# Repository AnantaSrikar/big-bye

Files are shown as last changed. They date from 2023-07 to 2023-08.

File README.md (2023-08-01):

# big-bye
A project that encompasses (almost) all the knowledge and skills I acquired throughout my undergraduate degree, serving as a farewell gift! 

The skills / tools I used
- Programming (C. Python, bash, etc)
- Server Setup (Web server with HTTPS by Caddy)
- Network Setup (Its currently hosted on my HomeLab)
- Soldering (Perfboard and SMD)
- PCB Desigining
- 3D Modelling (A case was supposed to be designed, didn't happen due to logistical issues)

## Components
- [Firmware](/firmware/)
- [Web Server](/web_server/)

You can find a demo of the project [here](https://youtu.be/nfPE4j3Xo48)!

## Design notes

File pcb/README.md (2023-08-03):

# PCB
Here are the KiCAD files for the PCB that I designed for this project.

You can find the BOM [here](bom.csv).

The ST7735 Display can be found at this [link](https://robu.in/product/1-8-inch-spi-128160-tft-lcd-display-module-pcb-arduino/).

## Schematic
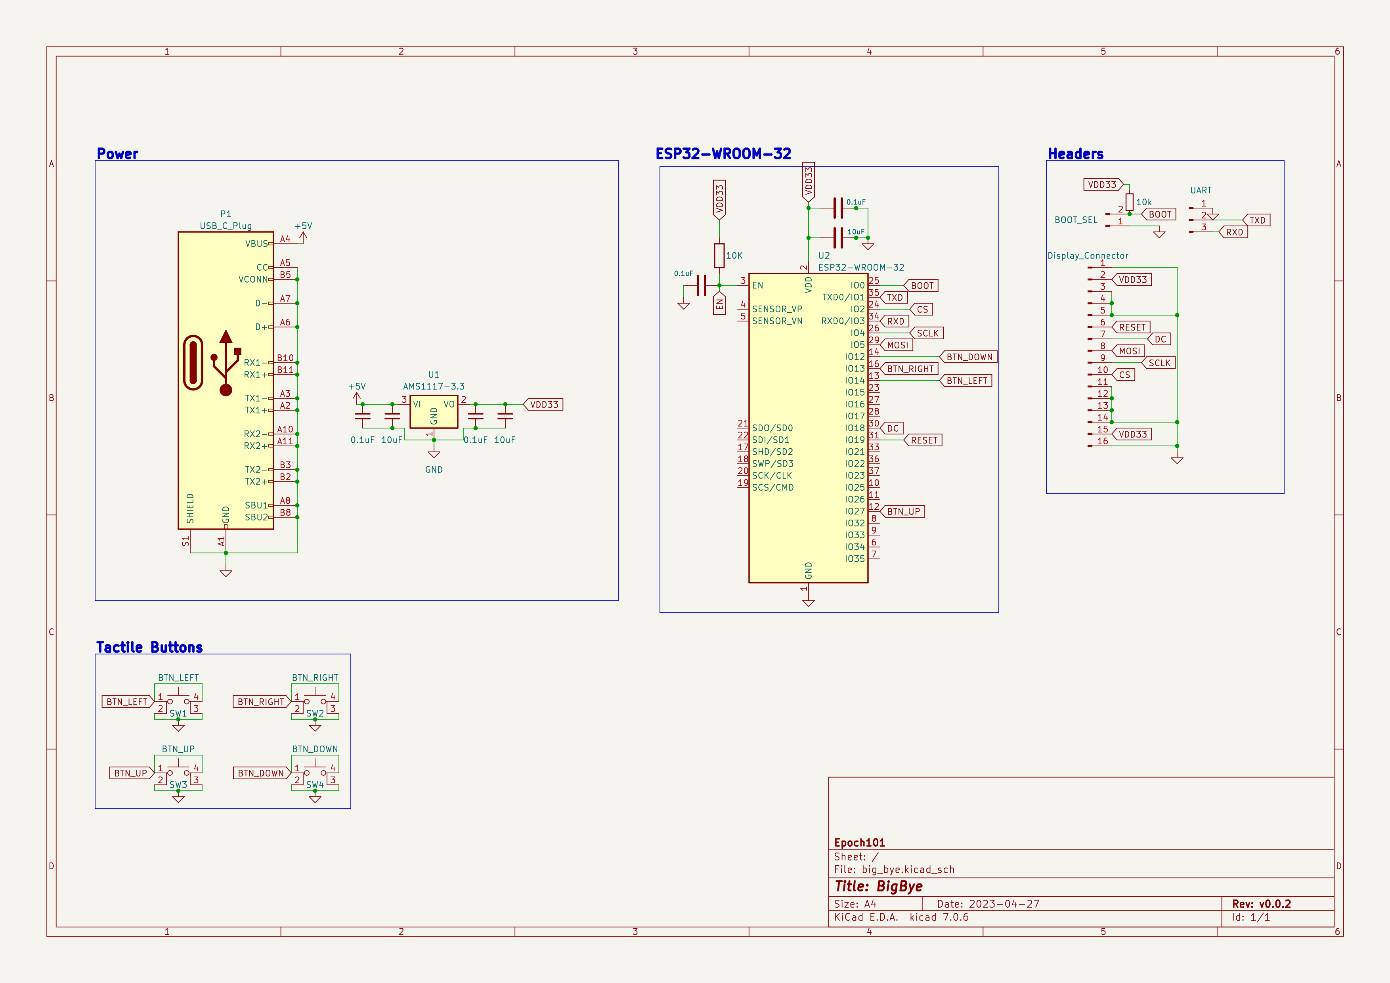
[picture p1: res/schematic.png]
The Schematic should be here, but not sure why it isn't :(


The PCB looks something like this:

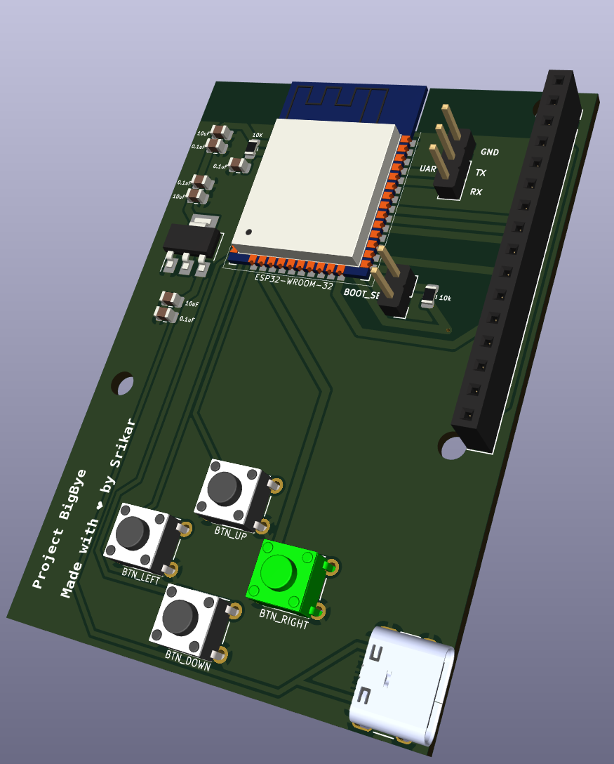
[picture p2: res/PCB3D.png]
The PCB should be here, but not sure why it isn't :(


You can watch a demo of the project in action (with the PCB and the display) [here](https://youtu.be/nfPE4j3Xo48)!

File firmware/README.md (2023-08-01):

# ESP32 Firmware

This firmware runs on the ESP32, which manages the Wi-Fi connection and fetches messages from a web server. These messages are then displayed on a TFT display.

## Features:
1. Dynamic WiFi Provisioning using ESP SoftAP Provisioning, available on both [Android](https://play.google.com/store/apps/details?id=com.espressif.provsoftap&hl=en&gl=US) and [iOS](https://apps.apple.com/ms/app/esp-softap-provisioning/id1474040630).
2. Dynamically loads the heading and messages onto the screen.
3. Support for combo button presses. Currently, UP + DOWN buttons work for resetting the board.
4. Works with BasicAuth for increased user privacy.

## Arduino IDE Setup
To run this on an ESP32, make sure the following settings are configured in the Arduino IDE:

1. Install the libraries mentioned in [dependencies.txt](/firmware/dependencies.txt).
2. Configure the Arduino IDE as shown below:

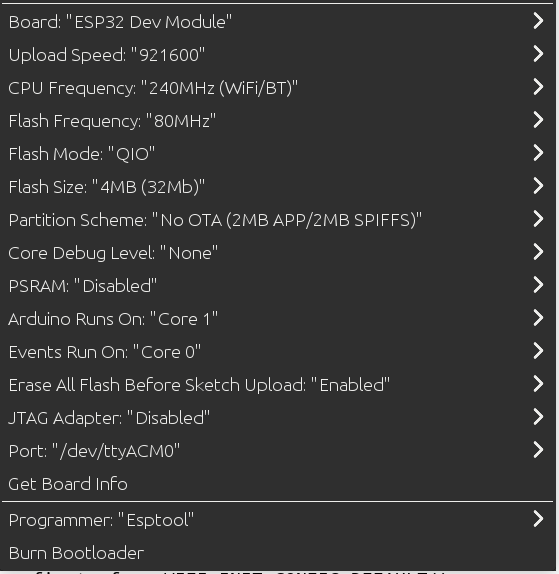
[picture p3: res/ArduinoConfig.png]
Arduino Config setting should be here, but not sure why it isn't :(


I'm using an ESP32-WROOM-32 with a 4MB Flash size; hence, I'm using the respective Partition Scheme to fit the application. Feel free to modify that as per your storage options.

## Flashing Firmware:
1. Set up your connection to the ESP32 via its UART port to flash it.
2. Make sure the ESP32 is booted in the Firmware Download Mode.
3. Select the right serial port in the Arduino IDE.
4. Modify `USERNAME`, `SERVER_ADDR`, `BASICAUTH_USERNAME`, and `BASICAUTH_PASSWORD` according to your [web server](../web_server) configuration.
5. Compile and wait for the flashing to be done.

## User Privacy
To ensure user privacy, the web server will be protected with BasicAuth using [Caddy](https://caddyserver.com/).

However, assigning usernames that are hard to guess will further increase privacy. For example, "somerandomdude-42069" would be hard to guess.

## Web Server
Head over [here](/web_server/) to set up your web server.

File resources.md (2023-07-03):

# Resources
## ESP32 Flashing
- https://www.reddit.com/r/esp32/comments/s8oeff/unable_to_program_esp32_module_on_a_custom_board/
- https://www.reddit.com/r/esp32/comments/kd90uy/esp32wroom32_custom_pcb_not_working_schematic/
- https://www.reddit.com/r/esp32/comments/ih0qxz/my_first_esp32_custom_pcb/

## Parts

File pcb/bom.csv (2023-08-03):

Id | Designator | Footprint | Quantity | Designation | Supplier and ref
1 | R2 | R_0805_2012Metric | 1 | 10k
2 | C7,C5,C1 | C_0805_2012Metric | 3 | 10uF
3 | C4,C3,C2,C6 | C_0805_2012Metric | 4 | 0.1uF
4 | P1 | USB_C_Receptacle_HRO_TYPE-C-31-M-12 | 1 | USB_C_Plug
5 | J2 | PinHeader_1x02_P2.54mm_Vertical | 1 | BOOT_SEL
6 | SW3 | SW_TH_Tactile_Omron_B3F-10xx | 1 | BTN_UP
7 | U2 | ESP32-WROOM-32 | 1 | ESP32-WROOM-32
8 | J1 | PinHeader_1x03_P2.54mm_Vertical | 1 | UART
9 | J3 | PinSocket_1x16_P2.54mm_Vertical | 1 | Display_Connector
10 | SW1 | SW_TH_Tactile_Omron_B3F-10xx | 1 | BTN_LEFT
11 | SW4 | SW_TH_Tactile_Omron_B3F-10xx | 1 | BTN_DOWN
12 | R1 | R_0805_2012Metric | 1 | 10K
13 | U1 | SOT-223-3_TabPin2 | 1 | AMS1117-3.3
14 | SW2 | SW_TH_Tactile_Omron_B3F-10xx | 1 | BTN_RIGHT

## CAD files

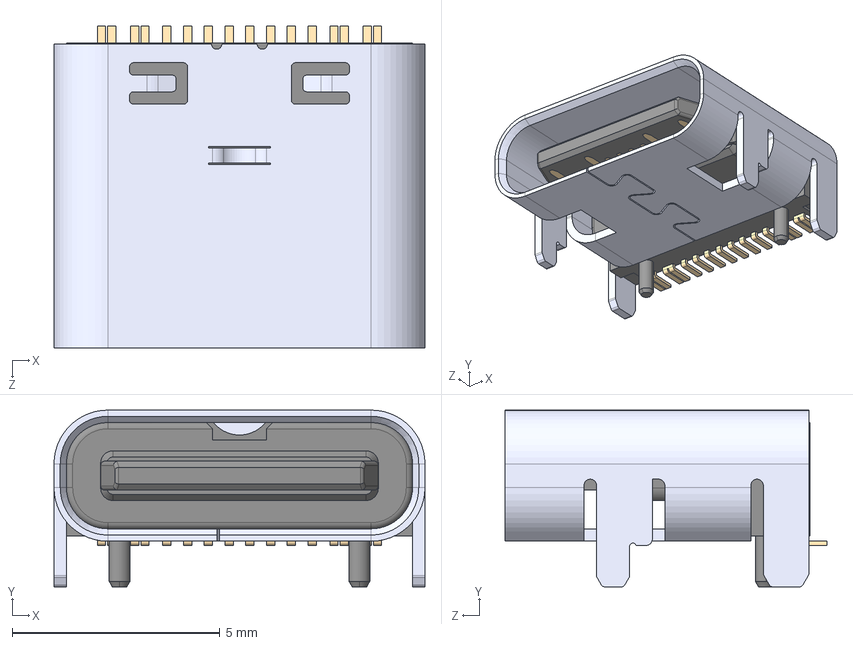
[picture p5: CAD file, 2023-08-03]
pcb/3d_models/CSP-USC16-TR--3DModel-STEP-468060.STEP
8.94 x 4.26 x 7.75 mm

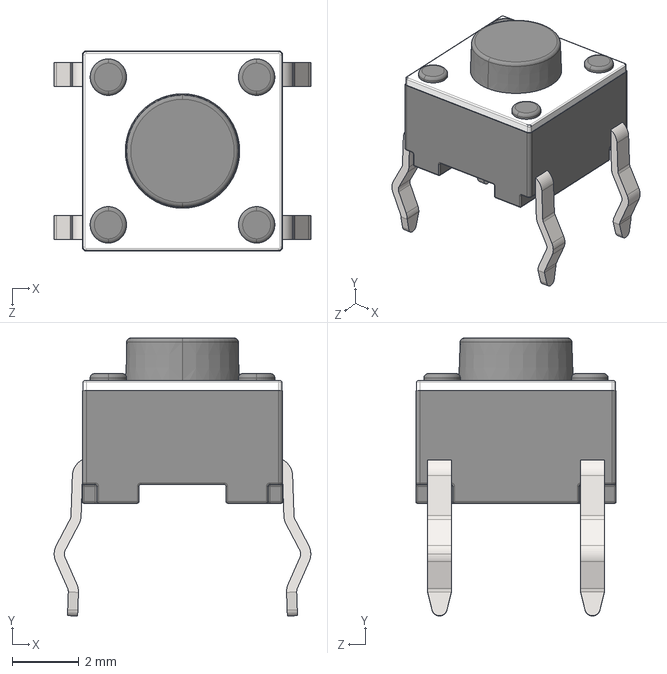
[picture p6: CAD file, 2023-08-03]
pcb/3d_models/tactile-switch-short-1.snapshot.1/tactileswitch-short/tactileswitch-short.STEP
7.69 x 8.33 x 6.01 mm

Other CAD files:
pcb/3d_models/tactile-switch-short-1.snapshot.1/tactileswitch-short/tactileswitch-short.IGS
pcb/3d_models/tactile-switch-short-1.snapshot.1/tactileswitch-short/tactileswitch-short.SLDPRT
pcb/3d_models/tactile-switch-short-1.snapshot.1/tactileswitch-short/tactileswitch-short.STL
pcb/3d_models/tactile-switch-short-1.snapshot.1/tactileswitch-short/tactileswitch-short.x_t

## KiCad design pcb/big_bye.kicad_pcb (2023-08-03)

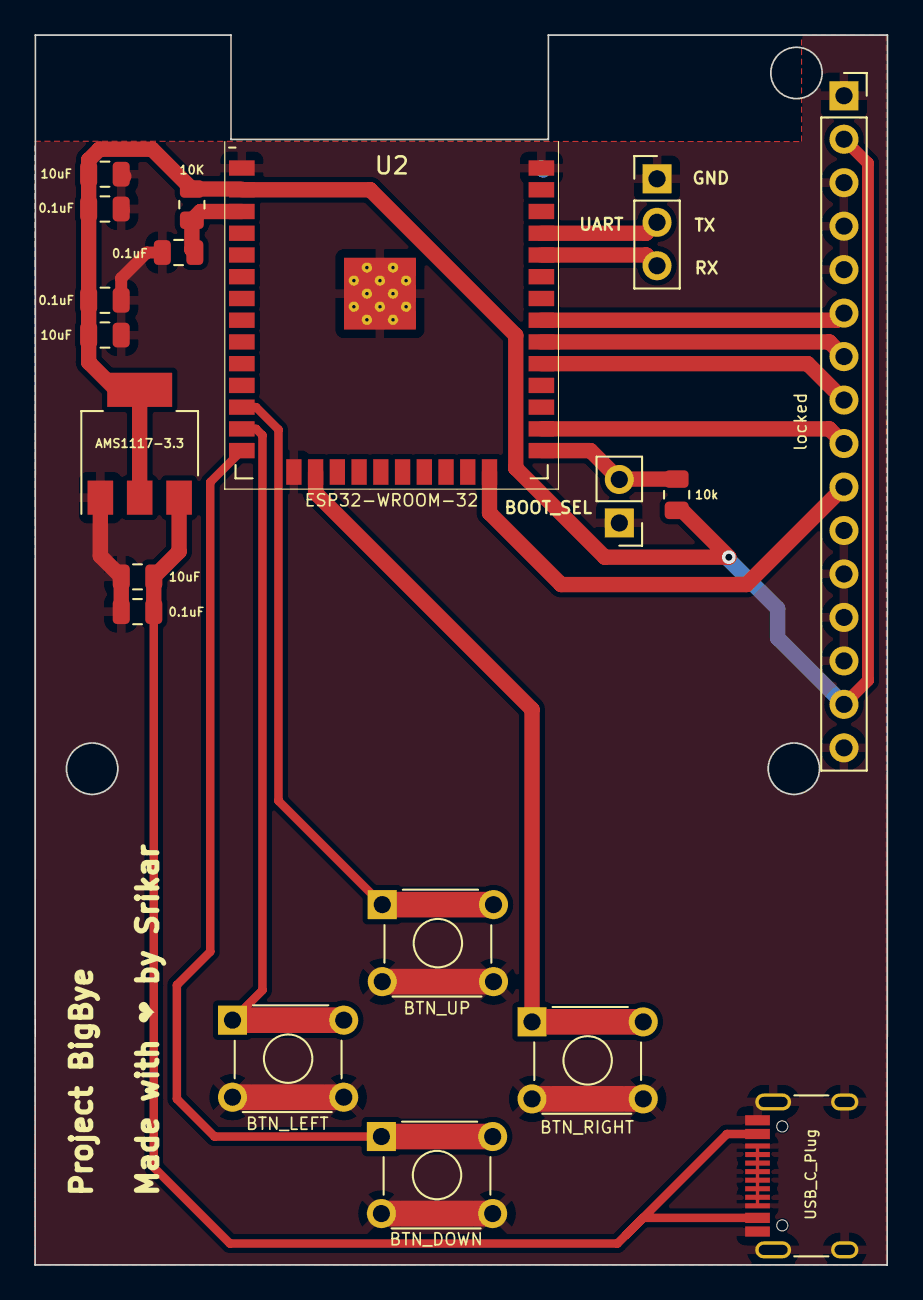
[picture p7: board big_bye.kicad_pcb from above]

Board: 2 copper layers, 49.8 x 71.9 mm, 19 parts (0 on the bottom side), 16 nets.

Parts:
C1, C5, C7: 10uF; C_0805_2012Metric
C2, C3, C4, C6: 0.1uF; C_0805_2012Metric
J1: UART; PinHeader_1x03_P2.54mm_Vertical
J2: BOOT_SEL; PinHeader_1x02_P2.54mm_Vertical
J3: locked; PinSocket_1x16_P2.54mm_Vertical
P1: USB_C_Plug; USB_C_Receptacle_HRO_TYPE-C-31-M-12
R1: 10K; R_0805_2012Metric
R2: 10k; R_0805_2012Metric
SW1: BTN_LEFT; SW_TH_Tactile_Omron_B3F-10xx
SW2: BTN_RIGHT; SW_TH_Tactile_Omron_B3F-10xx
SW3: BTN_UP; SW_TH_Tactile_Omron_B3F-10xx
SW4: BTN_DOWN; SW_TH_Tactile_Omron_B3F-10xx
U1: AMS1117-3.3; SOT-223-3_TabPin2
U2: ESP32-WROOM-32

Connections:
+5V: C4.1, C5.1, P1.A4 (VBUS), P1.A9 (VBUS), P1.B4 (VBUS), P1.B9 (VBUS), U1.3 (VI)
BOOT: J2.2, R2.2, U2.25 (IO0)
BTN_DOWN: SW4.1, U2.14 (IO12)
BTN_LEFT: SW1.1, U2.13 (IO14)
BTN_RIGHT: SW2.1, U2.16 (IO13)
BTN_UP: SW3.1, U2.12 (IO27)
CS: J3.10, U2.24 (IO2)
DC: J3.7, U2.30 (IO18)
EN: C3.2, R1.1, U2.3 (EN)
GND: C1.2, C2.2, C3.1, C4.2, C5.2, C6.2, C7.2, J1.1, J2.1, J3.1, J3.3, J3.4, J3.5, J3.11, J3.12, J3.13, J3.14, J3.16, P1.A1 (GND), P1.A5 (CC), P1.A6 (D+), P1.A7 (D-), P1.A8 (SBU1), P1.A12 (GND), P1.B1 (GND), P1.B5 (VCONN), P1.B8 (SBU2), P1.B12 (GND), P1.S1 (SHIELD), SW1.2, SW2.2, SW3.2, SW4.2, U1.1 (GND), U2.1 (GND), U2.15 (GND), U2.38 (GND), U2.39 (GND)
MOSI: J3.8, U2.29 (IO5)
RESET: J3.6, U2.31 (IO19)
RXD: J1.3, U2.34 (RXD0/IO3)
SCLK: J3.9, U2.26 (IO4)
TXD: J1.2, U2.35 (TXD0/IO1)
VDD33: C1.1, C2.1, C6.1, C7.1, J3.2, J3.15, R1.2, R2.1, U1.2 (VO), U2.2 (VDD)

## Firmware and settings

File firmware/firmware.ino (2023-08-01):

/**
 * @file firmware.ino
 * @author Ananta Srikar
 * @brief Firmware that run on the ESP32 (4MB) to manage WiFi and Display messages on the ST7735 Display
 * @version 0.3
 * @date 2023-05-28
 * 
 * @copyright Copyright (c) 2023
 * 
 */

#include <WiFiProv.h>
#include <WiFi.h>
#include <esp_wifi.h>
#include <SPI.h>
#include <TFT_eSPI.h>
#include <qrcode_espi.h>
#include <HTTPClient.h>
#include <ArduinoJson.h>	// Make sure v5.13.4 is installed

// Modify as per your setup
#define USERNAME "user"
#define SERVER_ADDR "https://yourwebdomain.here.com"
#define BASICAUTH_USERNAME	"basicAuthUsername"
#define BASICAUTH_PASSWORD	"basicAuthPassword"

// Each character width is approximately 6 pixels with text size 1
#define LTR_PXL	6

#define BTN_LEFT	14
#define BTN_RIGHT	13
#define BTN_UP		27
#define BTN_DOWN	12

#define JSON_PARSE_CAP 2048

int reconnect_try = 0;
bool is_prov_needed = false;
bool is_qr_displayed = false;
bool has_IP_addr = false;

bool isBTNup = false;
bool isBTNdown = false;
bool isBTNleft = false;
bool isBTNright = false;

String user_server_addr = "";
bool refetch_needed = true;
int cur_msg_num = 1;
int num_msgs = 0;

// Display setup
TFT_eSPI display = TFT_eSPI();
QRcode_eSPI qrcode(&display);

// Finding the center Y coordinate. NOTE: Width and heigth parameters interchanged before switching to landscape
int Y_CENTER = (display.width() / 2) - LTR_PXL;

// JSON parser setup
StaticJsonBuffer<JSON_PARSE_CAP> JSONBuffer;

/**
 * @brief Function that erases WiFi credentials
 * 
 */
void eraseAllWiFiCredentials()
{
	wifi_init_config_t cfg = WIFI_INIT_CONFIG_DEFAULT();
	esp_wifi_init(&cfg); //initiate and allocate wifi resources (does not matter if connection fails)
	delay(2000); //wait a bit
	if(esp_wifi_restore() != ESP_OK)
	{
		Serial.println("WiFi is not initialized by esp_wifi_init ");
	}
	else
	{
		Serial.println("WiFi Configurations Cleared!");
	}
	
	delay(1000);

	ESP.restart();
}

/**
 * @brief Function to lock ESP and prevent accidnetal DOSing of server or itself
 * 
 */
void lockESP()
{
	displayCenter("Something is awfully wrong!", Y_CENTER, true);

	// Put the ESP32 into a locked state with no further processing
	is_prov_needed = true;
	is_qr_displayed = true;
}

/**
 * @brief Function that handles ESP32's WiFi
 * 
 * @param sys_event Arduino event that is linked to Wifi
 */
void SysProvEvent(arduino_event_t *sys_event)
{
	switch (sys_event->event_id)
	{
		case ARDUINO_EVENT_WIFI_STA_GOT_IP:
			Serial.print("\nConnected IP address : ");
			Serial.println(IPAddress(sys_event->event_info.got_ip.ip_info.ip.addr));
			has_IP_addr = true;
			break;

		case ARDUINO_EVENT_WIFI_STA_DISCONNECTED:
			Serial.println("\nDisconnected. Connecting to the AP again... ");
			reconnect_try++;

			// Try reprovisioning if unable to connect
			if(reconnect_try > 3)
			{
				reconnect_try = 0;
				eraseAllWiFiCredentials();
			}
			break;

		case ARDUINO_EVENT_PROV_START:
			Serial.println("\nProvisioning started\nGive Credentials of your access point using \" Android app \"");
			is_prov_needed = true;
			break;

		case ARDUINO_EVENT_PROV_CRED_RECV:
			Serial.println("\nReceived Wi-Fi credentials");
			Serial.print("\tSSID : ");
			Serial.println((const char *) sys_event->event_info.prov_cred_recv.ssid);
			Serial.print("\tPassword : ");
			Serial.println((char const *) sys_event->event_info.prov_cred_recv.password);
		
			displayCenter("Received WiFi credentials!", Y_CENTER, true);
			break;
		
		case ARDUINO_EVENT_PROV_CRED_FAIL:
			Serial.println("\nProvisioning failed!\nPlease reset to factory and retry provisioning\n");
			if(sys_event->event_info.prov_fail_reason == WIFI_PROV_STA_AUTH_ERROR)
			{
				Serial.println("\nWi-Fi AP password incorrect");
				displayCenter("WiFi Password incorrect!", Y_CENTER, true);
			}
			else
			{
				displayCenter("WiFi AP not found!", Y_CENTER, true);
				Serial.println("\nWi-Fi AP not found....Add API \" nvs_flash_erase() \" before beginProvision()");
			}
			delay(1000);
			eraseAllWiFiCredentials();
			break;
		
		case ARDUINO_EVENT_PROV_CRED_SUCCESS:
			Serial.println("\nProvisioning Successful");
			break;
		
		case ARDUINO_EVENT_PROV_END:
			Serial.println("\nProvisioning Ends");
			displayCenter("Provisioning Complete!", Y_CENTER, true);
			delay(1000);
			is_prov_needed = false;
			break;
		
		default:
			break;
	}
}

/**
 * @brief Funtion that runs a HTTPS get request on a specified URL
 * 
 * @param url URL to run the GET request on
 * @return String output of the GET request
 */
String getHTTPS(String url)
{
	HTTPClient http;

	// Set the Authorization header
	http.setAuthorization(BASICAUTH_USERNAME, BASICAUTH_PASSWORD);

	// Run the HTTP get
	http.begin(url);
	int httpCode = http.GET();

	// HTTP code will be negative on error
	if(httpCode > 0)
	{
		Serial.printf("[HTTP] GET - code: %d\n", httpCode);
		
		// If asomething unexpected happens, lock up system
		if(httpCode != HTTP_CODE_OK)
		{
			lockESP();
			return "ERROR";
		}

		// Return the result of the request if everything went well
		return http.getString();
	}

	else
	{
		Serial.printf("[HTTP] GET - error: %s\n", http.errorToString(httpCode).c_str());
		return "ERROR";
	}

	http.end();
}

/**
 * @brief Funtion to fetch and update the number of messages available for a user
 */
void updateNumMsgsForUser()
{
	String str_num_msgs = getHTTPS(user_server_addr);
	num_msgs = str_num_msgs.toInt();

	// Something is wrong in DB, or username is incorrect, or BasicAuth creds failed
	if(num_msgs == 0 && !is_prov_needed)
	{
		refetch_needed = false;
		Serial.println("0 detected again, locking!");
		
		lockESP();
		return;
	}
}

/**
 * @brief Get the X coord for the text to print at the center
 * 
 * @param text The text you want to display
 * @return int the X coordinate to print text on the display
 */
int getCenterXcoord(String text)
{
	// Each character width is approximately 6 pixels with text size 1
	int x_coord = (display.width() - (text.length() * LTR_PXL)) / 2;

	if(x_coord < 0 || x_coord > display.width())
	{
		return 0;
	}

	return x_coord;
}

/**
 * @brief Function to display the QR code when provisioning is needed
 * 
 */
void displayProvQRcode()
{
	qrcode.init();

	String qr_prov = "{\"ver\":\"v1\",\"name\":\"PROV_BIGBYE\",\"pop\":\"";
	qr_prov += USERNAME;
	qr_prov += "\",\"transport\":\"softap\"}";
	qrcode.create(qr_prov);

	display.setTextSize(1);
	display.setTextColor(TFT_BLACK, TFT_WHITE);
	display.drawString("Scan with ESP SoftAP Prov", 5, 5, 1);
	display.drawString("WiFi connection required!", 5, 118, 1);
}

/**
 * @brief Function that wraps words on the TFT disply
 * 
 * @param text The text you want to print on the screen
 */
void printWithWordWrap(String text)
{
	int wordStart = 0;
	int wordEnd = 0;
	while((text.indexOf(' ', wordStart) >= 0) && ( wordStart <= text.length()))
	{
		wordEnd = text.indexOf(' ', wordStart + 1);
		uint16_t len = display.textWidth(text.substring(wordStart, wordEnd));
		if(display.getCursorX() + len >= display.width())
		{
			display.println();
			if (wordStart > 0)
			{
				wordStart++;
			}
		}
		display.print(text.substring(wordStart, wordEnd));
		wordStart = wordEnd;
	}
}

/**
 * @brief Displays text at the center of the screen, at given Y coordinate
 * 
 * @param screenText Text that needs to be displayed at the center
 */
void displayCenter(String screenText, int y_coord, bool wipe_screen)
{
	if(wipe_screen)
	{
		display.fillScreen(TFT_WHITE);
	}

	display.setTextSize(1);
	display.setTextColor(TFT_BLACK, TFT_WHITE);
	display.drawString(screenText, getCenterXcoord(screenText), y_coord, 1);
}

/**
 * @brief Function that updates the display with the right message number
 * 
 */
void updateDisplayWithMsg()
{
	// Get the full message
	String cur_msg_url = user_server_addr;
	cur_msg_url += "/";
	cur_msg_url += String(cur_msg_num);

	// Get current Message JSON and parse it
	JsonObject& parsed = JSONBuffer.parseObject(getHTTPS(cur_msg_url));

	if(!parsed.success())
	{
		Serial.println("\n\nJSON parsing failed!\n\n");
		delay(5000);
	}

	String heading = parsed["heading"];
	String msg = parsed["msg"];

	display.fillScreen(TFT_WHITE);
	display.setTextSize(1);
	display.setTextColor(TFT_BLACK, TFT_WHITE);

	// Display heading
	displayCenter(heading, 5, true);
	
	// Display the message
	display.setCursor(0, 20);
	printWithWordWrap(msg);

	// Display msg number
	String footer = String(cur_msg_num) + "/" + String(num_msgs);
	displayCenter(footer, display.height() - LTR_PXL - 2, false);
}

/**
 * @brief Setup the board before running it
 */
void setup()
{
	// Run UART at 115200 baud rate.
	Serial.begin(115200);

	// Diplay initialisation
	display.init();
	display.setRotation(3);
	display.fillScreen(TFT_WHITE);
	displayCenter("Initialising...", Y_CENTER, true);

	// Setup BTN Inputs
	pinMode(BTN_LEFT, INPUT_PULLUP);
	pinMode(BTN_RIGHT, INPUT_PULLUP);
	pinMode(BTN_UP, INPUT_PULLUP);
	pinMode(BTN_DOWN, INPUT_PULLUP);

	// WiFi 
	WiFi.onEvent(SysProvEvent);
	WiFiProv.beginProvision(WIFI_PROV_SCHEME_SOFTAP, WIFI_PROV_SCHEME_HANDLER_NONE, WIFI_PROV_SECURITY_1, USERNAME, "PROV_BIGBYE");

	// User specific URL
	user_server_addr = SERVER_ADDR;
	user_server_addr += "/user/";
	user_server_addr += USERNAME;

	// Wait till we attempt to connect to WiFi
	delay(2000);

	if(!is_prov_needed)
	{
		// Wait till we get IP address. 
		// Note to self: Spin locks are terrible btw, please use better sync methods in future
		while(!has_IP_addr)
		{
			delay(50);
		}
		updateNumMsgsForUser();
	}
}

/**
 * @brief Runs forever after the setup
 */
void loop()
{
	// Read input buttons
	isBTNup = digitalRead(BTN_UP);
	isBTNdown = digitalRead(BTN_DOWN);
	isBTNleft = digitalRead(BTN_LEFT);
	isBTNright = digitalRead(BTN_RIGHT);

	// Update number of messages for a user if we don't have it already
	if(num_msgs == 0 && !is_prov_needed)
	{
		updateNumMsgsForUser();
	}

	// Combo Buttons (high priority, will come first)
	if(isBTNdown == LOW && isBTNup == LOW)
	{
		Serial.println("Combo button press!");
		displayCenter("Factory reset board?", Y_CENTER, true);
		displayCenter("Press up button to confirm", Y_CENTER + LTR_PXL * 2, false);
		displayCenter("Press down to to cancel", Y_CENTER + LTR_PXL * 4, false);
		delay(2000);
		while(true)
		{
			isBTNup = digitalRead(BTN_UP);
			isBTNdown = digitalRead(BTN_DOWN);

			if(isBTNdown == LOW)
			{
				displayCenter("Reset canceled. Refreshing...", Y_CENTER, true);
				delay(1500);
				refetch_needed = true;
				break;
			}

			else if(isBTNup == LOW)
			{
				displayCenter("Resetting board now...", Y_CENTER, true);
				eraseAllWiFiCredentials();
			}
		}
	}

	// Pre WiFi Provisioning checks
	if(is_prov_needed)
	{
		if(!is_qr_displayed)
		{
			displayProvQRcode();
			is_qr_displayed = true;
		}

		delay(1000);
		return;
	}

	// Since provisioning is done
	is_qr_displayed = false;

	// Single button presses (low priority, to be used after message loads)

	if(isBTNleft == LOW)
	{
		Serial.println("Left button press detected");

		if(cur_msg_num > 1)
		{
			cur_msg_num--;
		}

		// Display that you're viewing the first message if already on first message
		else if(cur_msg_num == 1)
		{
			displayCenter("You're at the first message!", Y_CENTER, true);
			delay(1000);
		}

		refetch_needed = true;
		delay(100);
	}

	else if(isBTNright == LOW)
	{
		Serial.println("Right button press detected");

		if(cur_msg_num < num_msgs)
		{
			cur_msg_num++;
		}

		// Display that you're viewing the last message if already on last message
		else if (cur_msg_num == num_msgs)
		{
			displayCenter("You're at the last message!", Y_CENTER, true);
			delay(1000);
		}

		refetch_needed = true;
		delay(100);
	}

	// Refetch and update display only when needed!
	if(refetch_needed)
	{
		// Refetch and update display

		displayCenter("Fetching....", Y_CENTER, true);

		updateDisplayWithMsg();

		refetch_needed = false;
	}

	delay(50);
}

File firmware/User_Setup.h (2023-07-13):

/**
 * @file User_Setup.h
 * @author Ananta Srikar
 * @brief Configuration file for ST7735 SPI based display to be used with TFT_eSPI Library
 * @version 0.2
 * @date 2023-07-13
 * 
 * @copyright Copyright (c) 2023
 * 
 */
// Setup for the ESP32 with ST7735 128x160 display

#define USER_SETUP_ID 70

#define ST7735_DRIVER

// #define TFT_SDA_READ // Display has a bidirectional SDA pin (no MISO)

#define TFT_WIDTH  128
#define TFT_HEIGHT 160

#define TFT_MOSI 5
#define TFT_SCLK 4
#define TFT_CS    2  // Chip select control pin
#define TFT_DC    18 // Data Command control pin
#define TFT_RST   19  // Reset pin (could connect to RST pin)

#define LOAD_GLCD
#define LOAD_FONT2
#define LOAD_FONT4
#define LOAD_FONT6
#define LOAD_FONT7
#define LOAD_FONT8
#define LOAD_GFXFF

#define SMOOTH_FONT

#define SPI_FREQUENCY       27000000
#define SPI_READ_FREQUENCY  16000000

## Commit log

2023-05-29 Firmware: WiFi provisioning with QR done - Added necessary arduino library dependencies - Added display related configs - Added useful references
2023-07-03 Firmware: Added button press event - Docs: Added ESP32 flashing reference
2023-07-10 Firmware: Firmware more efficient with display and web activity - Web_server: Modified DB structure for easier access on firmware - Web_server: Added get_num_msgs() endpoint for easier display on ESP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
2023-07-10 Firmware: Display message heading at centre - Switching between messages also working - TODO: Button press to interrupt later
2023-07-13 Firmware: Fixed display bug - Refactored code to have similar functions together - Added Library version in dependencies.txt - Fixed bug with message switching
    [User_Setup.h, firmware.ino]
2023-07-13 Firmware: Fixed word wrap bug - Added message number footer - Modified displayCenter for dynamic y-axis coords and screenwipe
    [firmware.ino]
2023-07-14 Firmware: Tiny bugfixes and improvements - Added BasicAuth for improved privacy - We now wait till we get an IP address to run a GET request - Improved error message display on screen
    [firmware.ino]
2023-07-14 Firmware: Added board reset and fixed more bugs - Removed unnecessary debug prints
    [firmware.ino]
2023-07-14 Firmware: Fixed bug with HTTP request
    [firmware.ino]
2023-08-03 PCB: Added final PCB design with more docs
    [CSP-USC16-TR--3DModel-STEP-468060.STEP, big_bye.kicad_pcb, big_bye.kicad_sch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]
